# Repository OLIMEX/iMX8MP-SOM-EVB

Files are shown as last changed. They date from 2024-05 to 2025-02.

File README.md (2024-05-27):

# iMX8MP-SOM-EVB

Development board for i.MX8MPlus System on Module with iMX8 SOC

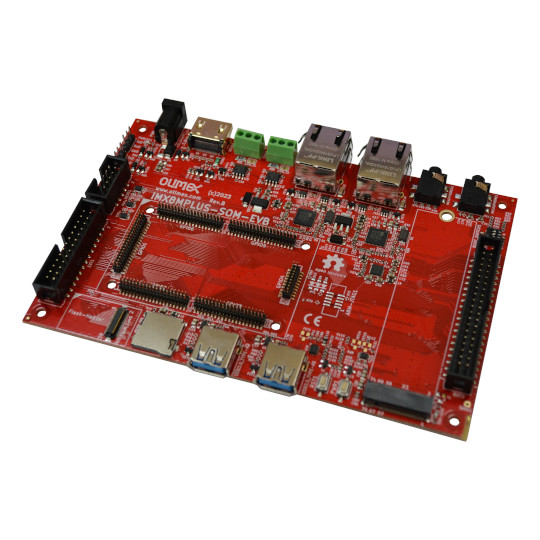
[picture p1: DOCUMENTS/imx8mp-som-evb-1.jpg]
imx8mp-som-evb-1


https://www.olimex.com/Products/SOM/NXP-iMX8/iMX8MP-SOM-EVB-IND/

https://www.olimex.com/Products/SOM/NXP-iMX8/iMX8MP-SOM-4GB-IND/open-source-hardware

## Licensee
* Hardware is released under CERN Open Hardware Licence Version 2 - Strongly Reciprocal
* Software is released under GPL V3 Licensee
* Documentation is released under CC BY-SA 4.0

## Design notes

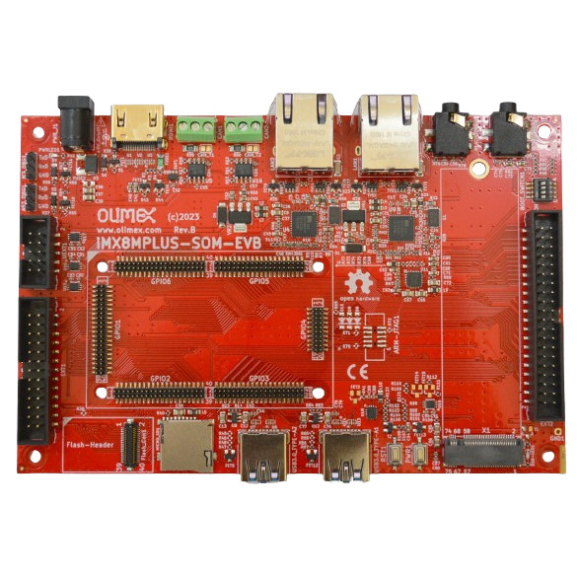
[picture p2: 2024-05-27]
DOCUMENTS/imx8mp-som-evb-2.jpg

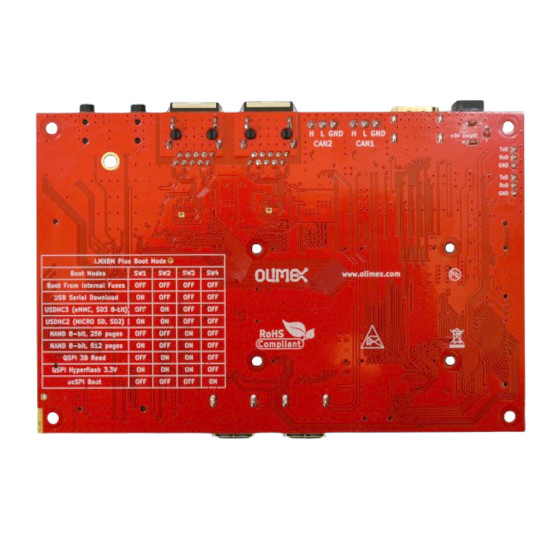
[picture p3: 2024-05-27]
DOCUMENTS/imx8mp-som-evb-3.jpg

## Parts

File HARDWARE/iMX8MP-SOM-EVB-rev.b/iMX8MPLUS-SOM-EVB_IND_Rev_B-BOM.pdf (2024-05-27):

iMX8MPLUS-SOM-EVB_IND_Rev_B | 05/24/2023

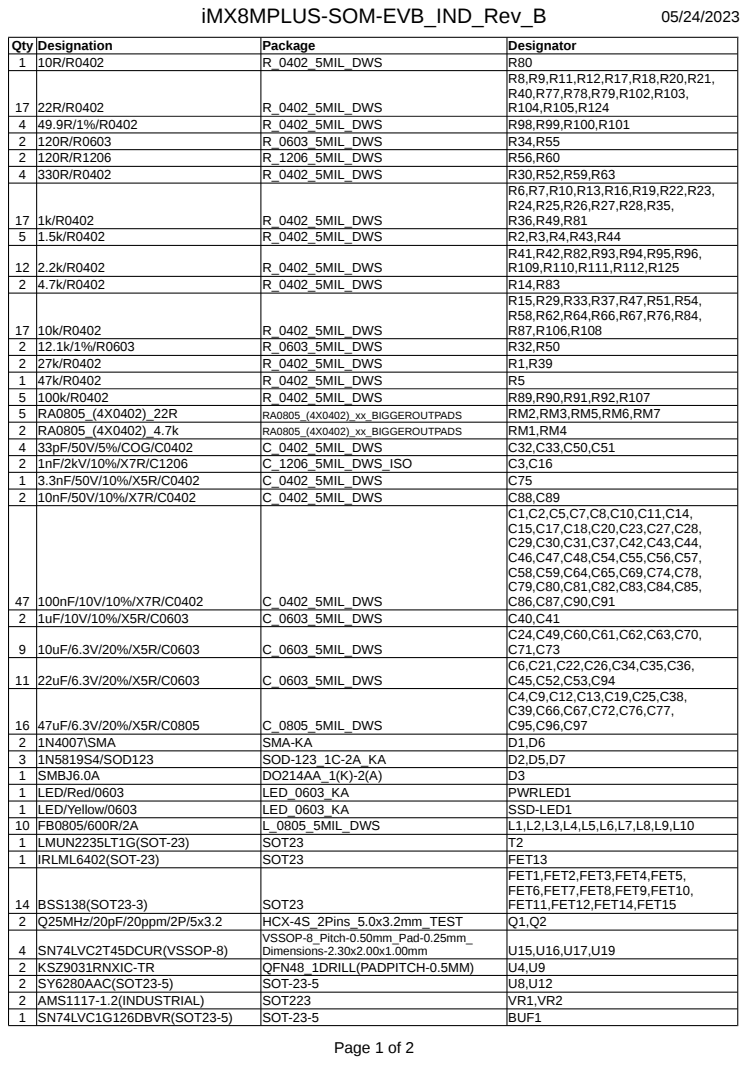
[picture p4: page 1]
Qty Designation; Package; Designator; R_0402_5MIL_DWS; R_0603_5MIL_DWS; R_1206_5MIL_DWS; RA0805_(4X0402)_xx_BIGGEROUTPADS; 4 33pF/50V/5%/COG/C0402; C_0402_5MIL_DWS; C_1206_5MIL_DWS_ISO; C_0603_5MIL_DWS; C_0805_5MIL_DWS; 2 1N4007\SMA; SMA-KA; 3 1N5819S4/SOD123; SOD-123_1C-2A_KA; 1 SMBJ6.0A; 1 LED/Red/0603; LED_0603_KA; PWRLED1; 1 LED/Yellow/0603; SSD-LED1; L_0805_5MIL_DWS; 1 LMUN2235LT1G(SOT-23); SOT23; 1 IRLML6402(SOT-23); FET13; 14 BSS138(SOT23-3); 2 Q25MHz/20pF/20ppm/2P/5x3.2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

iMX8MPLUS-SOM-EVB_IND_Rev_B | 05/24/2023
2 MCP2562-E/SN(SOIC-8_150mil) | SOIC-8_150mil | U5,U10
1 ES8388(QFN28) | QFN28_EP(29)4.076x4.076x0.9mmPitch0.45mm | U11
1 DSC557-0344FE1T(QFN-14) | QFN-14_3.20x2.50x0.9mm_Pitch_0.5mm | U18
1 P-B-V-40-LF | GBH-254-SMT-40 | EXT2
1 P-B-V-10-LF | GBH-254-SMT-10 | UEXT1
5 MALE-PAV16X-2x20-HIGH | GPH127SMT-02X20(PA-V16X-2X20-LF)
1 MALE-PAV16X-2x10-HIGH | GPH127SMT-02X10(PA-V16X-2X10-LF) | GPIO4
2 PJ-3.5-365-3P(SCJ325P00XG0B02G) | SCJ325P00XG0B02G | HEADPHONES1,MICROPHONE1
1 HDMI-SWM-19 | HDMI-SWM-19 | HDMI1
1 Flash_Con[DF12(3.0)-40DS-0.5V(86)] | Flash_Con[DF12(3.0)-40DS-0.5V(86)] | Flash_Con1
2 TM211Q01FM22 | TM211Q01FM22 | LAN1,LAN2
1 MICRO_SD(TFC-WPAPR-08) | TFC-WPAPR-08 | MICRO_SD1
1 PWRJ-2mm(YDJ-1134) | PWRJ-2mm(YDJ-1134) | PWR_J1
2 HN1x3 | HN1x3 | A53_DBG1,M7_DBG1
2 TB3-3.5mm | TB3-3.5mm | CAN1,CAN2
1 B-V-26-LF(GBH254SMT-26) | GBH-254-SMT-26 | EXT1
1 SSD-M2(APCI0107-P001A) | m.2_M(NGFF-W42R-5809-LF) | X1
2 USB-SWZ1BL-9A-LF | USB3.0-TypeA(USB-SWZ1BL-9A-LF)
1 FSMD035 | FUSE-1206 | FUSE1
1 DSHP04TS-S | DSHP04TS-S-1.27mm_Half_4_Slide | BOOT_SWITCH1
2 T1107A(6x3,8x2,5MM) | T1107A(6x3,8x2,5MM) | PWR1,RST1
4 ESDS314DBVR(SOT-23-5) | SOT-23-5 | TVS1,TVS2,TVS3,TVS4
2 Opened | SJ | CAN_T1,CAN_T2
1 NA(5025) | FUSE-5025 | FUSE2
3 NA(RCLAMP0524P(SLP2510P8)) | SLP2510P8_TEST | U1,U2,U3
13 NA/R0402 | R_0402_5MIL_DWS
4 NA(ESD5304D-10/TR) | SLP2510P8_TEST | U6,U7,U13,U14
1 NA(22R/R0402) | R_0402_5MIL_DWS | R38
5 NA(10k/R0402) | R_0402_5MIL_DWS | R65,R68,R69,R70,R71
1 NA(HAB-VCR-010-LF) | HAB-VCR-010-LF | ARM-JTAG1
3 NA(1N5819S4/SOD123) | SOD-123_1C-2A_KA | D8,D9,D10
1 NA(100nF/10V/10%/X7R/C0402) | C_0402_5MIL_DWS | C68
1 NA(R0402) | R_0402_5MIL_DWS | R75
1 NA(2.2k/R0402) | R_0402_5MIL_DWS | R97
2 NA(0R/R0402) | R_0402_5MIL_DWS | R121,R122
1 NA(LMUN2211LT1G(SOT-23)) | SOT23 | T1
1 NA(47uF/6.3V/20%/X5R/C0805) | C_0805_5MIL_DWS | C98

GPIO1,GPIO2,GPIO3,
GPIO5,GPIO6

USB3.0_TYPE-A2,
USB3.0_TYPE-A1

R31,R45,R46,R48,R53,R57,R61, R72,R73,R74,R85,R86,R88

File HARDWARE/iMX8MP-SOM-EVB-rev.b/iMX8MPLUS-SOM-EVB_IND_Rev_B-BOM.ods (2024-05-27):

Qty | Designation | Package | Designator
1 | 10R/R0402 | R_0402_5MIL_DWS | R80
17 | 22R/R0402 | R_0402_5MIL_DWS | R8,R9,R11,R12,R17,R18,R20,R21, R40,R77,R78,R79,R102,R103, R104,R105,R124
4 | 49.9R/1%/R0402 | R_0402_5MIL_DWS | R98,R99,R100,R101
2 | 120R/R0603 | R_0603_5MIL_DWS | R34,R55
2 | 120R/R1206 | R_1206_5MIL_DWS | R56,R60
4 | 330R/R0402 | R_0402_5MIL_DWS | R30,R52,R59,R63
17 | 1k/R0402 | R_0402_5MIL_DWS | R6,R7,R10,R13,R16,R19,R22,R23, R24,R25,R26,R27,R28,R35, R36,R49,R81
5 | 1.5k/R0402 | R_0402_5MIL_DWS | R2,R3,R4,R43,R44
12 | 2.2k/R0402 | R_0402_5MIL_DWS | R41,R42,R82,R93,R94,R95,R96, R109,R110,R111,R112,R125
2 | 4.7k/R0402 | R_0402_5MIL_DWS | R14,R83
17 | 10k/R0402 | R_0402_5MIL_DWS | R15,R29,R33,R37,R47,R51,R54, R58,R62,R64,R66,R67,R76,R84, R87,R106,R108
2 | 12.1k/1%/R0603 | R_0603_5MIL_DWS | R32,R50
2 | 27k/R0402 | R_0402_5MIL_DWS | R1,R39
1 | 47k/R0402 | R_0402_5MIL_DWS | R5
5 | 100k/R0402 | R_0402_5MIL_DWS | R89,R90,R91,R92,R107
5 | RA0805_(4X0402)_22R | RA0805_(4X0402)_xx_BIGGEROUTPADS | RM2,RM3,RM5,RM6,RM7
2 | RA0805_(4X0402)_4.7k | RA0805_(4X0402)_xx_BIGGEROUTPADS | RM1,RM4
4 | 33pF/50V/5%/COG/C0402 | C_0402_5MIL_DWS | C32,C33,C50,C51
2 | 1nF/2kV/10%/X7R/C1206 | C_1206_5MIL_DWS_ISO | C3,C16
1 | 3.3nF/50V/10%/X5R/C0402 | C_0402_5MIL_DWS | C75
2 | 10nF/50V/10%/X7R/C0402 | C_0402_5MIL_DWS | C88,C89
47 | 100nF/10V/10%/X7R/C0402 | C_0402_5MIL_DWS | C1,C2,C5,C7,C8,C10,C11,C14, C15,C17,C18,C20,C23,C27,C28, C29,C30,C31,C37,C42,C43,C44, C46,C47,C48,C54,C55,C56,C57, C58,C59,C64,C65,C69,C74,C78, C79,C80,C81,C82,C83,C84,C85, C86,C87,C90,C91
2 | 1uF/10V/10%/X5R/C0603 | C_0603_5MIL_DWS | C40,C41
9 | 10uF/6.3V/20%/X5R/C0603 | C_0603_5MIL_DWS | C24,C49,C60,C61,C62,C63,C70, C71,C73
11 | 22uF/6.3V/20%/X5R/C0603 | C_0603_5MIL_DWS | C6,C21,C22,C26,C34,C35,C36, C45,C52,C53,C94
16 | 47uF/6.3V/20%/X5R/C0805 | C_0805_5MIL_DWS | C4,C9,C12,C13,C19,C25,C38, C39,C66,C67,C72,C76,C77, C95,C96,C97
2 | 1N4007\SMA | SMA-KA | D1,D6
3 | 1N5819S4/SOD123 | SOD-123_1C-2A_KA | D2,D5,D7
1 | SMBJ6.0A | DO214AA_1(K)-2(A) | D3
1 | LED/Red/0603 | LED_0603_KA | PWRLED1
1 | LED/Yellow/0603 | LED_0603_KA | SSD-LED1
10 | FB0805/600R/2A | L_0805_5MIL_DWS | L1,L2,L3,L4,L5,L6,L7,L8,L9,L10
1 | LMUN2235LT1G(SOT-23) | SOT23 | T2
1 | IRLML6402(SOT-23) | SOT23 | FET13
14 | BSS138(SOT23-3) | SOT23 | FET1,FET2,FET3,FET4,FET5, FET6,FET7,FET8,FET9,FET10, FET11,FET12,FET14,FET15
2 | Q25MHz/20pF/20ppm/2P/5x3.2 | HCX-4S_2Pins_5.0x3.2mm_TEST | Q1,Q2
4 | SN74LVC2T45DCUR(VSSOP-8) | VSSOP-8_Pitch-0.50mm_Pad-0.25mm_ Dimensions-2.30x2.00x1.00mm | U15,U16,U17,U19
2 | KSZ9031RNXIC-TR | QFN48_1DRILL(PADPITCH-0.5MM) | U4,U9
2 | SY6280AAC(SOT23-5) | SOT-23-5 | U8,U12
2 | AMS1117-1.2(INDUSTRIAL) | SOT223 | VR1,VR2
1 | SN74LVC1G126DBVR(SOT23-5) | SOT-23-5 | BUF1
2 | MCP2562-E/SN(SOIC-8_150mil) | SOIC-8_150mil | U5,U10
1 | ES8388(QFN28) | QFN28_EP(29)4.076x4.076x0.9mmPitch0.45mm | U11
1 | DSC557-0344FE1T(QFN-14) | QFN-14_3.20x2.50x0.9mm_Pitch_0.5mm | U18
1 | P-B-V-40-LF | GBH-254-SMT-40 | EXT2
1 | P-B-V-10-LF | GBH-254-SMT-10 | UEXT1
5 | MALE-PAV16X-2x20-HIGH | GPH127SMT-02X20(PA-V16X-2X20-LF) | GPIO1,GPIO2,GPIO3, GPIO5,GPIO6
1 | MALE-PAV16X-2x10-HIGH | GPH127SMT-02X10(PA-V16X-2X10-LF) | GPIO4
2 | PJ-3.5-365-3P(SCJ325P00XG0B02G) | SCJ325P00XG0B02G | HEADPHONES1,MICROPHONE1
1 | HDMI-SWM-19 | HDMI-SWM-19 | HDMI1
1 | Flash_Con[DF12(3.0)-40DS-0.5V(86)] | Flash_Con[DF12(3.0)-40DS-0.5V(86)] | Flash_Con1
2 | TM211Q01FM22 | TM211Q01FM22 | LAN1,LAN2
1 | MICRO_SD(TFC-WPAPR-08) | TFC-WPAPR-08 | MICRO_SD1
1 | PWRJ-2mm(YDJ-1134) | PWRJ-2mm(YDJ-1134) | PWR_J1
2 | HN1x3 | HN1x3 | A53_DBG1,M7_DBG1
2 | TB3-3.5mm | TB3-3.5mm | CAN1,CAN2
1 | B-V-26-LF(GBH254SMT-26) | GBH-254-SMT-26 | EXT1
1 | SSD-M2(APCI0107-P001A) | m.2_M(NGFF-W42R-5809-LF) | X1
2 | USB-SWZ1BL-9A-LF | USB3.0-TypeA(USB-SWZ1BL-9A-LF) | USB3.0_TYPE-A2, USB3.0_TYPE-A1
1 | FSMD035 | FUSE-1206 | FUSE1
1 | DSHP04TS-S | DSHP04TS-S-1.27mm_Half_4_Slide | BOOT_SWITCH1
2 | T1107A(6x3,8x2,5MM) | T1107A(6x3,8x2,5MM) | PWR1,RST1
4 | ESDS314DBVR(SOT-23-5) | SOT-23-5 | TVS1,TVS2,TVS3,TVS4
2 | Opened | SJ | CAN_T1,CAN_T2
1 | NA(5025) | FUSE-5025 | FUSE2
3 | NA(RCLAMP0524P(SLP2510P8)) | SLP2510P8_TEST | U1,U2,U3
13 | NA/R0402 | R_0402_5MIL_DWS | R31,R45,R46,R48,R53,R57,R61, R72,R73,R74,R85,R86,R88
4 | NA(ESD5304D-10/TR) | SLP2510P8_TEST | U6,U7,U13,U14
1 | NA(22R/R0402) | R_0402_5MIL_DWS | R38
5 | NA(10k/R0402) | R_0402_5MIL_DWS | R65,R68,R69,R70,R71
1 | NA(HAB-VCR-010-LF) | HAB-VCR-010-LF | ARM-JTAG1
3 | NA(1N5819S4/SOD123) | SOD-123_1C-2A_KA | D8,D9,D10
1 | NA(100nF/10V/10%/X7R/C0402) | C_0402_5MIL_DWS | C68
1 | NA(R0402) | R_0402_5MIL_DWS | R75
1 | NA(2.2k/R0402) | R_0402_5MIL_DWS | R97
2 | NA(0R/R0402) | R_0402_5MIL_DWS | R121,R122
1 | NA(LMUN2211LT1G(SOT-23)) | SOT23 | T1
1 | NA(47uF/6.3V/20%/X5R/C0805) | C_0805_5MIL_DWS | C98

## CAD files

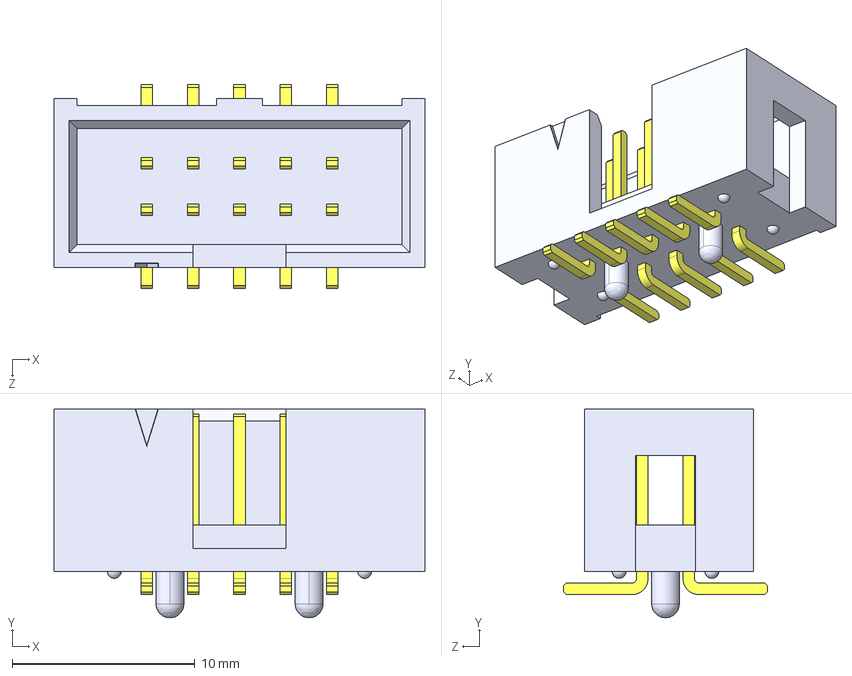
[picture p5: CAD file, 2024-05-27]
HARDWARE/iMX8MP-SOM-EVB-rev.b/3d/UEXT-SMD.STEP
20.3 x 11.4 x 11.2 mm
User Library-HTST-105-01-F-DV-A__HTST-105-01-DV-A_header
User Library-HTST-105-01-F-DV-A__HTST-First_Position_Indicator
User Library-HTST-105-01-F-DV-A__T-1S6-05-01-DV_

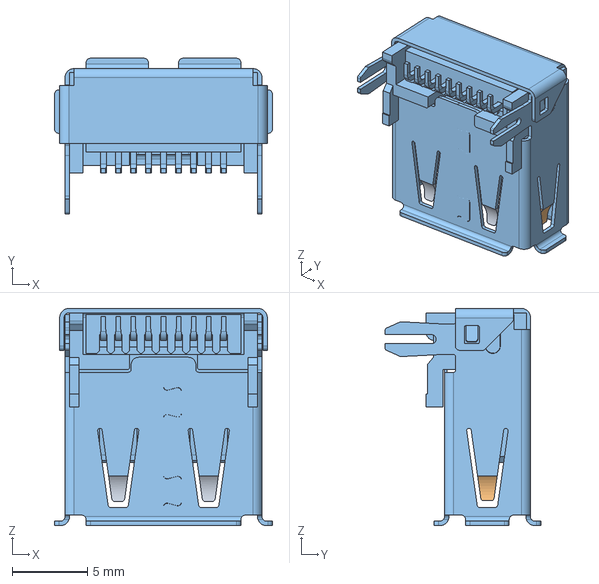
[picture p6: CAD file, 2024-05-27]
HARDWARE/iMX8MP-SOM-EVB-rev.b/3d/USB3.0-TypeA_SWZ1BL-9A.stp
14.5 x 10.3 x 14.4 mm

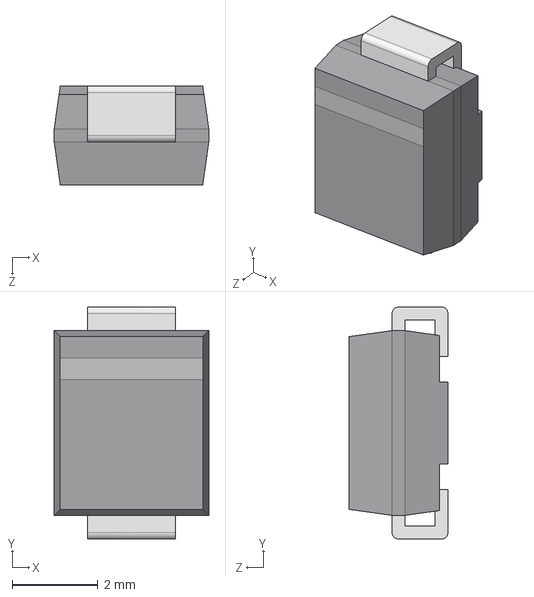
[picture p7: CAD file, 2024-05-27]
HARDWARE/iMX8MP-SOM-EVB-rev.b/3d/DO-214AA_SMB.step
3.60 x 5.40 x 2.30 mm

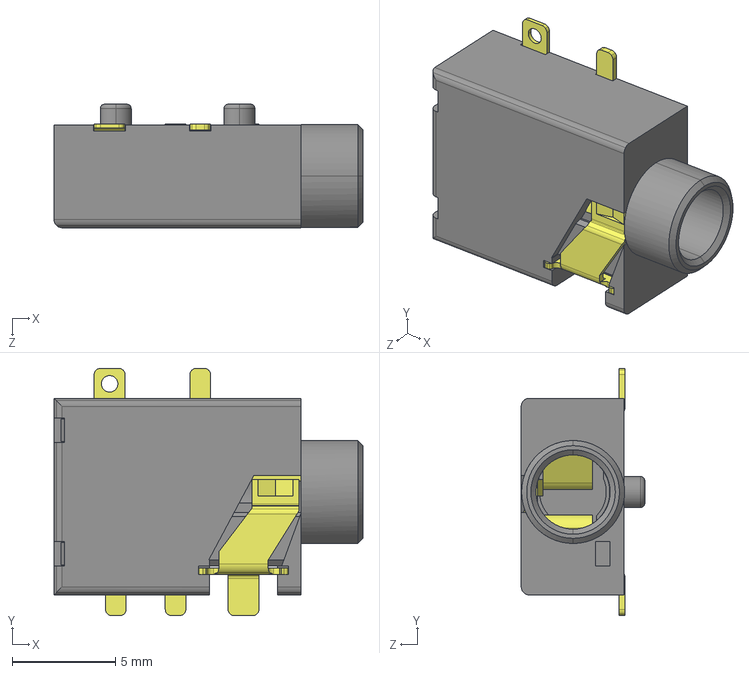
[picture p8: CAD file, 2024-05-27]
HARDWARE/iMX8MP-SOM-EVB-rev.b/3d/Audio_Jack-3.5mm---CUI_SJ1-3515-SMT-TR.step
15.0 x 12.0 x 6.00 mm

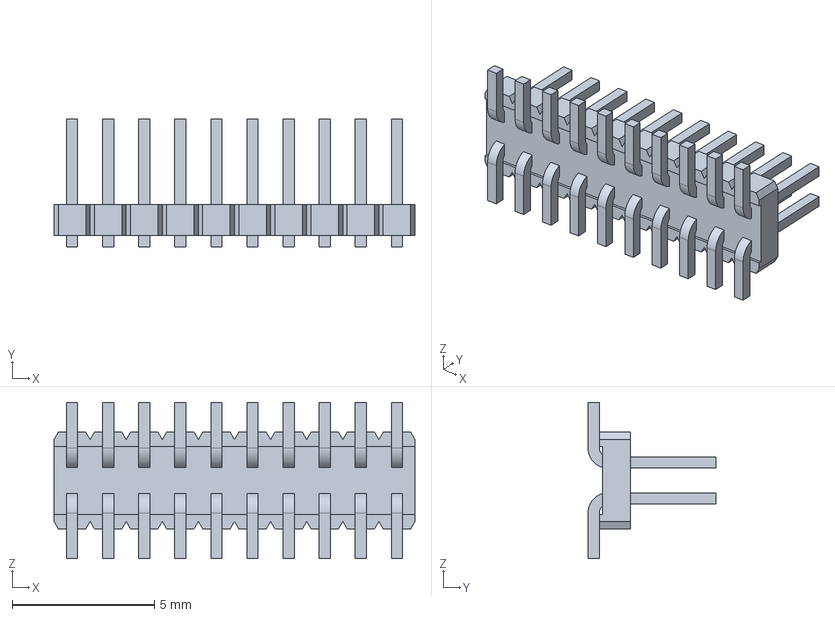
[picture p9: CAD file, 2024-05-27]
HARDWARE/iMX8MP-SOM-EVB-rev.b/3d/20PinMaleSmt.stp
12.7 x 4.50 x 5.50 mm

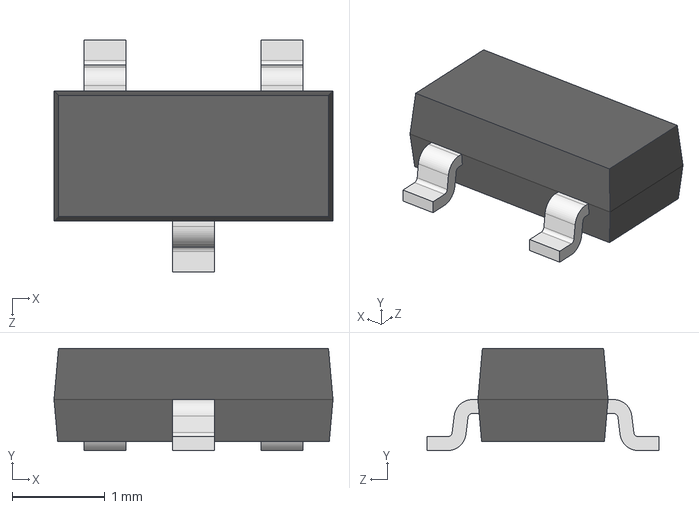
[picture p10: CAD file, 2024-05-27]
HARDWARE/iMX8MP-SOM-EVB-rev.b/3d/SOT-23.step
3.00 x 1.10 x 2.50 mm

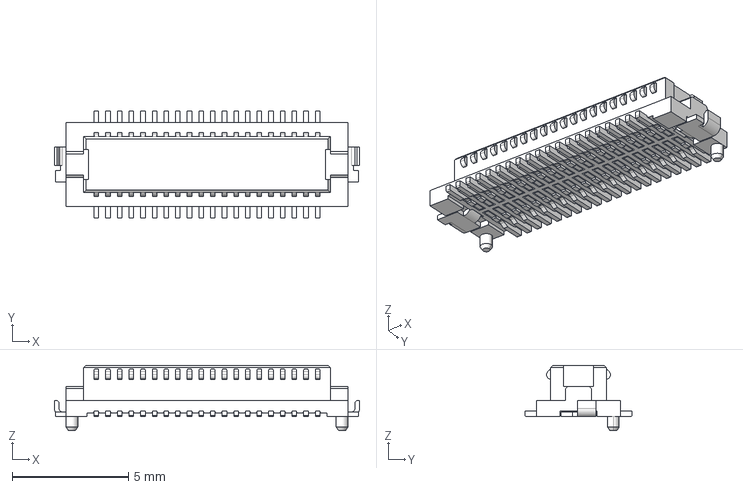
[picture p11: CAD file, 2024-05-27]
HARDWARE/iMX8MP-SOM-EVB-rev.b/3d/DF12(3.0)-40DS-0.5V.stp
13.1 x 4.60 x 2.80 mm

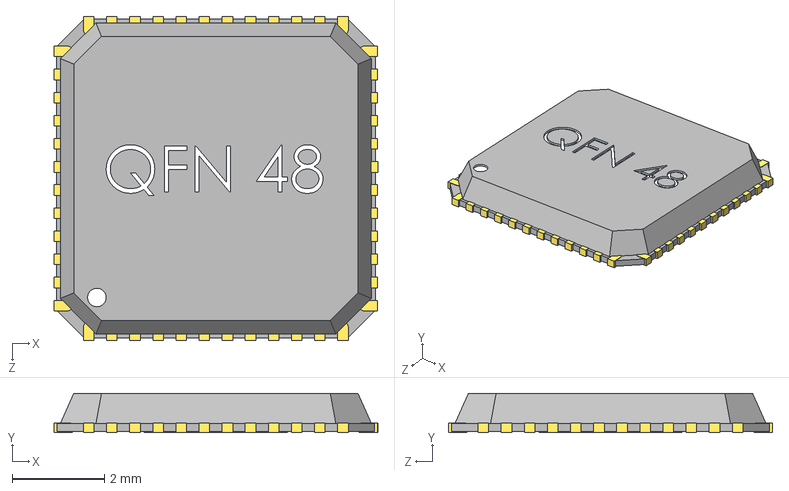
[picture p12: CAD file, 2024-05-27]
HARDWARE/iMX8MP-SOM-EVB-rev.b/3d/QFN48-0.5.STEP
7.00 x 0.85 x 7.01 mm
User Library-QFN48-1_Body
User Library-QFN48-1_Pins

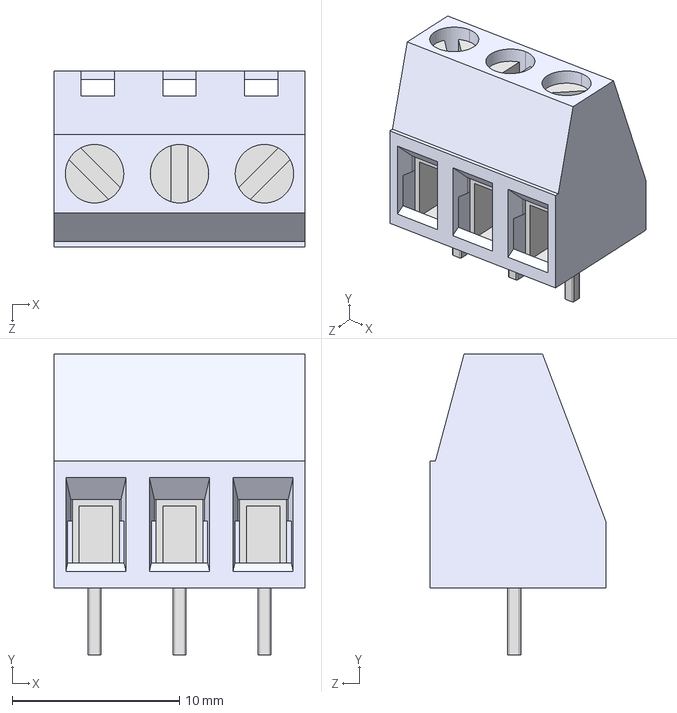
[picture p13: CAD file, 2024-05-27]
HARDWARE/iMX8MP-SOM-EVB-rev.b/3d/klema-5mm-3pin.step
15.0 x 18.0 x 10.5 mm

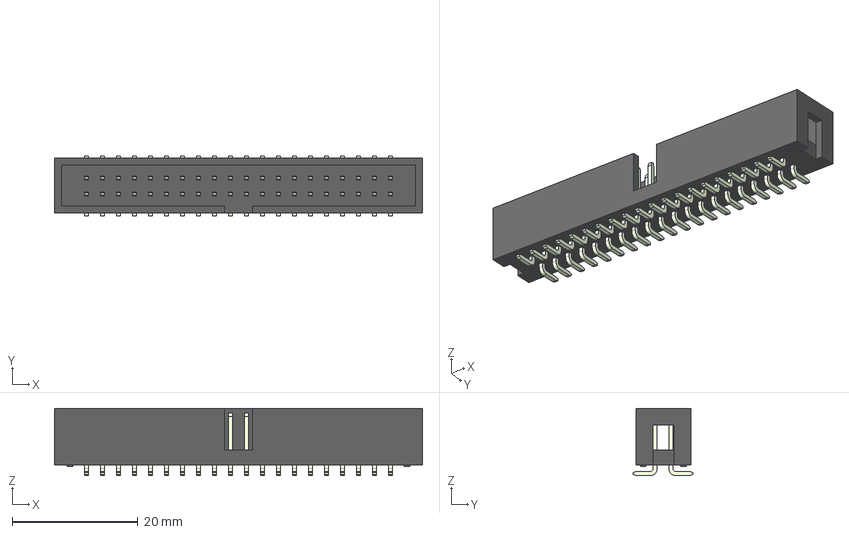
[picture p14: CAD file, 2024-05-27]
HARDWARE/iMX8MP-SOM-EVB-rev.b/3d/GBH254SMT-40(B-V-40-LF).stp
58.4 x 9.50 x 10.6 mm

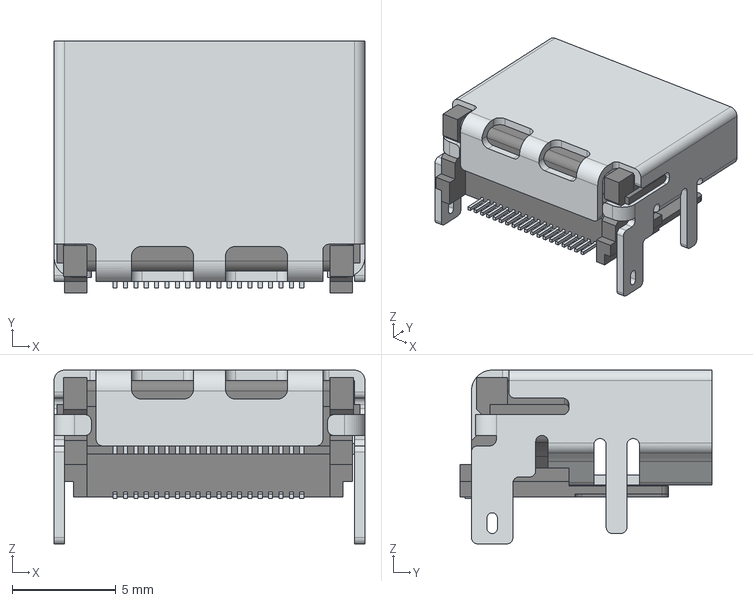
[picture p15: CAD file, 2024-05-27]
HARDWARE/iMX8MP-SOM-EVB-rev.b/3d/HDMI_19POS_SMD_Wurth_Electronic-685119134923.stp
15.0 x 12.2 x 8.38 mm

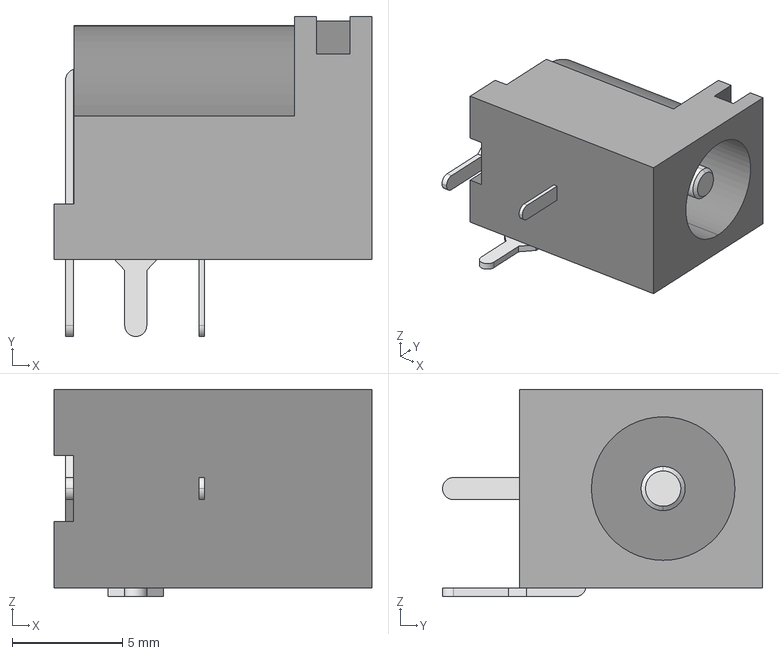
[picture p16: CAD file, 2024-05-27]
HARDWARE/iMX8MP-SOM-EVB-rev.b/3d/pj-102ah.stp
14.4 x 14.5 x 9.40 mm

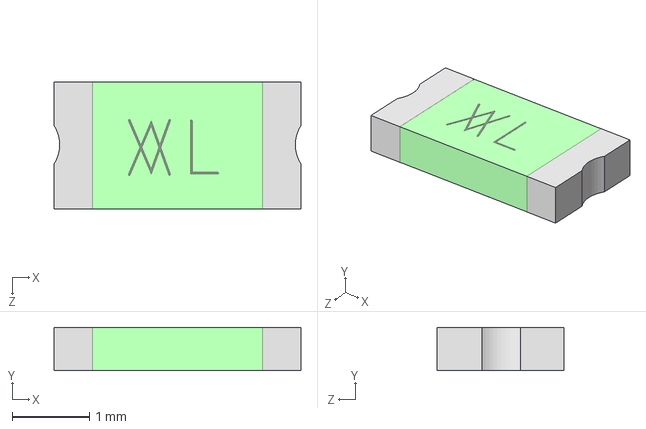
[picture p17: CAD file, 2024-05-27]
HARDWARE/iMX8MP-SOM-EVB-rev.b/3d/SMD075F.step
3.20 x 0.562 x 1.65 mm

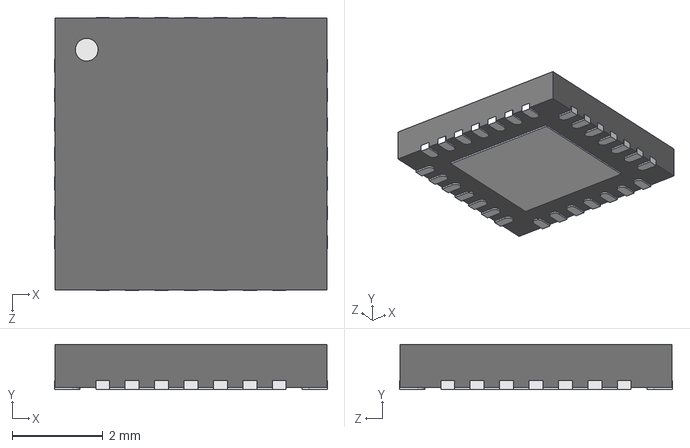
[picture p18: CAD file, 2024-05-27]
HARDWARE/iMX8MP-SOM-EVB-rev.b/3d/QFN-28(6.0x6.0x1.0mm_P0.65mm).STEP
6.02 x 1.00 x 6.02 mm

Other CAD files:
HARDWARE/iMX8MP-SOM-EVB-rev.b/3d/GBH2x5.stp
HARDWARE/iMX8MP-SOM-EVB-rev.b/3d/DO-214AC_SMA.step
HARDWARE/iMX8MP-SOM-EVB-rev.b/3d/SOT-23-5.step
HARDWARE/iMX8MP-SOM-EVB-rev.b/3d/TFC-WPAPR-08---112J-TXAR-R_C_1-1.STEP
HARDWARE/iMX8MP-SOM-EVB-rev.b/3d/40PinMaleSMD.stp
HARDWARE/iMX8MP-SOM-EVB-rev.b/3d/434121043836 (rev1).stp
HARDWARE/iMX8MP-SOM-EVB-rev.b/3d/Connector_1Port_RJ45_Magjack_10-100Base-T_AutoMDIX_Molex-0934635206_DigiKey-WM17614-ND.stp
HARDWARE/iMX8MP-SOM-EVB-rev.b/3d/GPH2x13.stp
HARDWARE/iMX8MP-SOM-EVB-rev.b/3d/HN1x3-PinHeader_1x03_P2.54mm_Vertical.step
HARDWARE/iMX8MP-SOM-EVB-rev.b/3d/M.2(NGFF)_Series_67-Contacts.stp
HARDWARE/iMX8MP-SOM-EVB-rev.b/3d/QFN-14_3.20x2.50mm(ASEMCC2-ZR-T3).STEP
HARDWARE/iMX8MP-SOM-EVB-rev.b/3d/SLP2510P8.step
HARDWARE/iMX8MP-SOM-EVB-rev.b/3d/SMD5032.STEP
HARDWARE/iMX8MP-SOM-EVB-rev.b/3d/SO-8_150mil---SN65HVDA1050AQDRQ1.STEP
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

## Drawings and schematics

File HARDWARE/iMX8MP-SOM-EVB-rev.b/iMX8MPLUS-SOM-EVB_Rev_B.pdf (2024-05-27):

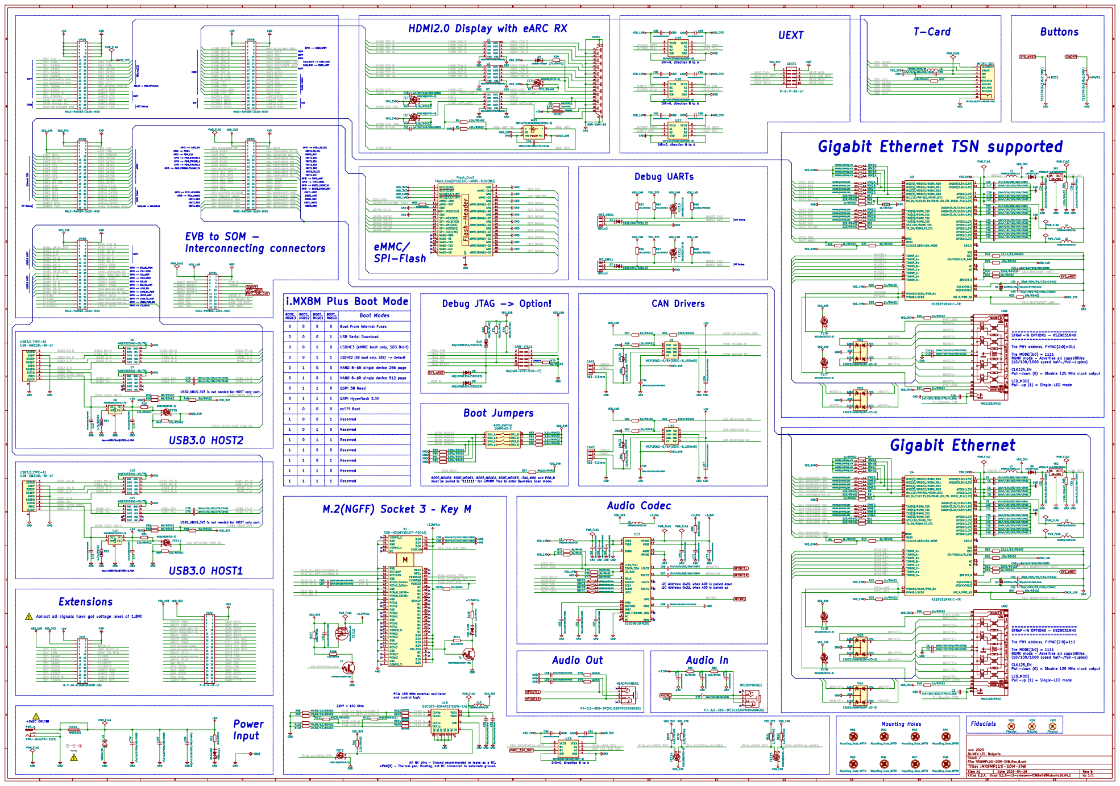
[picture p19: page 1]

8 OUT2 | HDMI_TX1_P

HDMI_TX2_N

8 OUT2 | HDMI_TXC_P
7 GND 6 OUT3 | HDMI_TXC_N

8 OUT2 | HSDA | 16
7 GND 6 OUT3 | | 17

GPIO -> DSI_BL_PWM
GPIO -> CSI1_SYNC GPIO -> CSI_nRST GPIO -> CSI2_SYNC GPIO -> DSI_EN GPIO -> DSI_TS_nINT GPIO -> LVDS_EN GPIO -> LVDS_BL_PWM

INT_N/PME_N2
DA+ DA- DB+ DB- DC+ DC- DD+ DD- GREEN

Boot From Internal Fuses

0 VBUS 1 USBDN 2 USBDP 3 GNDP 4 SSRXN 5 SSRXP 6 GNDD 7 SSTXN 8 SSTXP 9 USB3.0_TYPE-A2
USB-SWZ1BL-9A-LF

====================== The PHY address, PHYAD[2:0]=011

USDHC2 (SD boot only, SD2) -> Default

NAND 8-bit single device 256 page

Pull-down (0) = Disable 125 MHz clock output
LED_MODE
Pull-up (1) = Single-LED mode

NAND 8-bit single device 512 page

USB2_VBUS_3V3 is not needed for HOST only port.

0 VBUS 1 USBDN 2 USBDP 3 GNDP 4 SSRXN 5 SSRXP 6 GNDD 7 SSTXN 8 SSTXP 9 USB3.0_TYPE-A1

must be pulled to "111111" for i.MX8M Plus to enter Boundary Scan mode.

I2C Address: 0x22, when AD0 is pulled up

====================== The PHY address, PHYAD[2:0]=111

7 CLK1p 8 CLK1n 9 U18 DSC557-0344FE1T(QFN-14) GND C88 10nF/50V/10%/X7R/C0402 C89 10nF/50V/10%/X7R/C0402 GND GND

All NC pins - Ground recommended or leave as a NC.

ePAD(0) - Thermal pad, floating, not DC connected to substrate ground.

Id: 1/1 Title: iMX8MPLUS-SOM-EVB

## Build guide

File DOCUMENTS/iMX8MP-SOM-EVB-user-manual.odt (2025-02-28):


IMX8MP-SOM-EVB

User Manual

document revision 2.0 www.olimex.com

# What is iMX8MP-SOM-EVB

iMX8MP-SOM-EVB (https://www.olimex.com/Products/SOM/NXP-iMX8/iMX8MP-SOM-EVB-IND/) is an expansion board for easier evaluation of iMX8MP-SOM (https://www.olimex.com/Products/SOM/NXP-iMX8/iMX8MP-SOM-4GB-IND/open-source-hardware) system-on-module development board. It has:

- iMX8MP-SOM matching connectors
- Two Gigabit Ethernet connectors
- Two CAN transceivers
- HDMI output connector
- Power jack for 5V DC
- Two serial debug UARTs (for A53 and M7)
- Micro SD-card connector
- Flash module connector
- USB 3.0 hosts
- PCI Express 3.0 M.2 expansion slot (2280) for nVME
- Headphone 3.5mm connector
- Microphone 3.5 mm connector
- Reset button
- PWR button
- UEXT connector
- Two GPIO connectors
- Optional ARM JTAG connector
- Boot slide switch
- Industrial grade temperature range: (-45+85)C
- Dimensions: (155 x 102)mm
- Open-hardware design, all original design files available, design made with KiCAD

## Order codes for iMX8MP-SOM-EVB and accessories

iMX8MP-SOM-EVB (https://www.olimex.com/Products/SOM/NXP-iMX8/iMX8MP-SOM-EVB-IND/) Expansion board for easy evaluation of iMX8MP-SOM which can be used as reference design; requires SOM module iMX8MP- SOM-4GB-IND

iMX8MP-SOM-4GB-IND (https://www.olimex.com/Products/SOM/NXP-iMX8/iMX8MP-SOM-4GB-IND/open-source-hardware) Main module with i.MX8 quad-core MIMX8ML8CVNKZAB, 4GB LPDDR4, EEPROM, PMIC

MICRO-SD-16GB-CLASS10 (https://www.olimex.com/Products/Components/Storage/MICRO-SD-16GB-CLASS10/) Blank 16GB microSD card

USB-CARD-READER (https://www.olimex.com/Products/USB-Modules/USB-CARD-READER/) USB card reader and writer

SY1505E (https://www.olimex.com/Products/Power/SY1505E/) Power adapter 5V 3A

SY2005E (https://www.olimex.com/Products/Power/SY2005E/) Power adapter 5V 5A

USB-SERIAL-F (https://www.olimex.com/Products/Components/Cables/USB-Serial-Cable/USB-SERIAL-F/) Serial debug cable for console log

Flash-e32Gs16M (https://www.olimex.com/Products/OLinuXino/Accessories/Flash-e32Gs16M/) Plug-and-play eMMC and SPI memory expansion module

CABLE-HDMI-50CM (https://www.olimex.com/Products/Components/Cables/CABLE-HDMI-50CM/) HDMI cable

USB-KEYBOARD-PS2 (https://www.olimex.com/Products/USB-Modules/USB-KEYBOARD-PS2/) Mini keyboard

PWR-CABLE (https://www.olimex.com/Products/Components/Cables/PWR-CABLE/) Cable with free leads fitting the Olimex barrel jacks

UEXT modules (https://www.olimex.com/Products/Modules/) There are temperature, humidity, pressure, magnetic field, light sensors. Modules with LCDs, LED matrix, Relays, Bluetooth, Zigbee, WiFi, GSM, GPS, RFID, RTC, EKG, sensors and etc.

# HARDWARE

## iMX8MP-SOM-EVB layout


Flash module

MicroSD card

USB3 hosts

Reset Power Buttons

M.2 nVM slot

Power +5V

HDMI

CAN

Gigabit Ethernet

Audio

Boot

GPIO

UEXT

GPIO

Debug

Optional JTAG

## iMX8MP-SOM-EVB schematics

Latest PDF export of schematic is available at GitHub:

iMX8MP-SOM-EVB schematic PDF (https://github.com/OLIMEX/iMX8MP-SOM-EVB/blob/main/HARDWARE/iMX8MP-SOM-EVB-rev.b/iMX8MPLUS-SOM-EVB_Rev_B.pdf)

All design files and sources are again available at the GitHub page (https://github.com/OLIMEX/iMX8MP-SOM-EVB/tree/main/HARDWARE) of the device.

## iMX8MP-SOM-EVB connectors

### UEXT1 connector

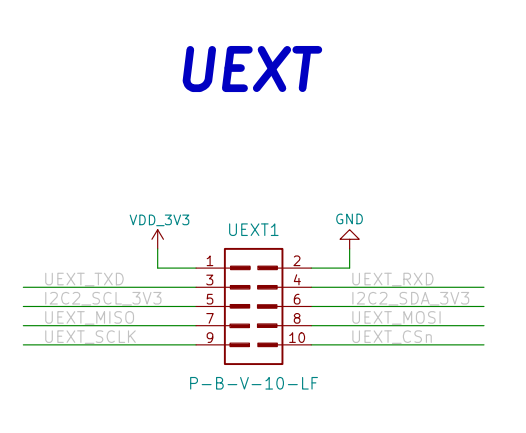
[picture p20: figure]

### Micro_SD1 connector

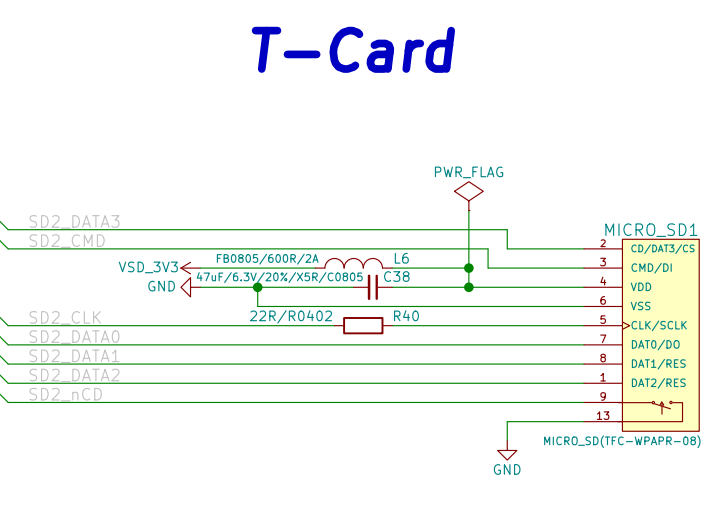
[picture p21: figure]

### Buttons

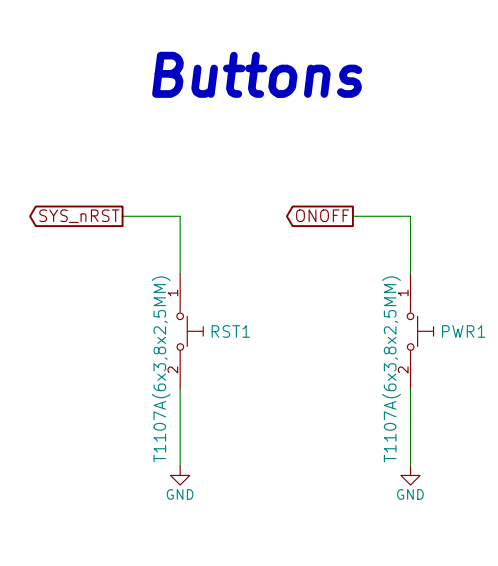
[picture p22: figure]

### EXT1 header

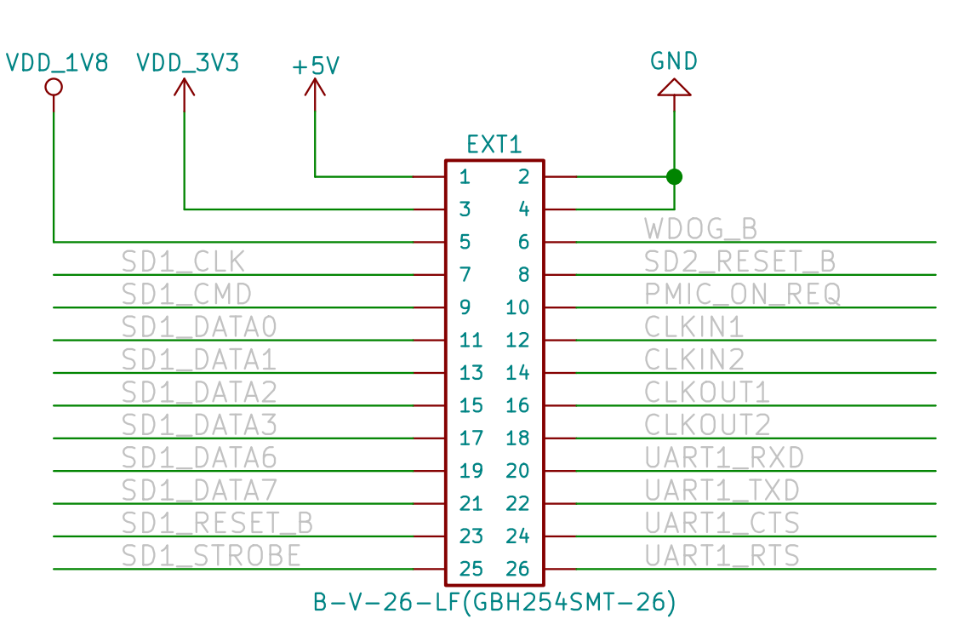
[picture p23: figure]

### EXT2 header

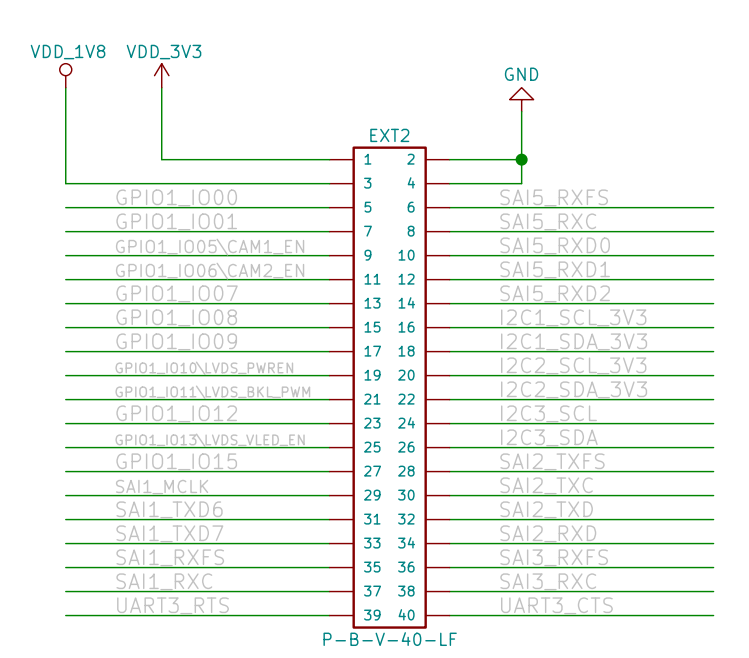
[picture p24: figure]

### PCI 3.0 M.2 (2280) nVME

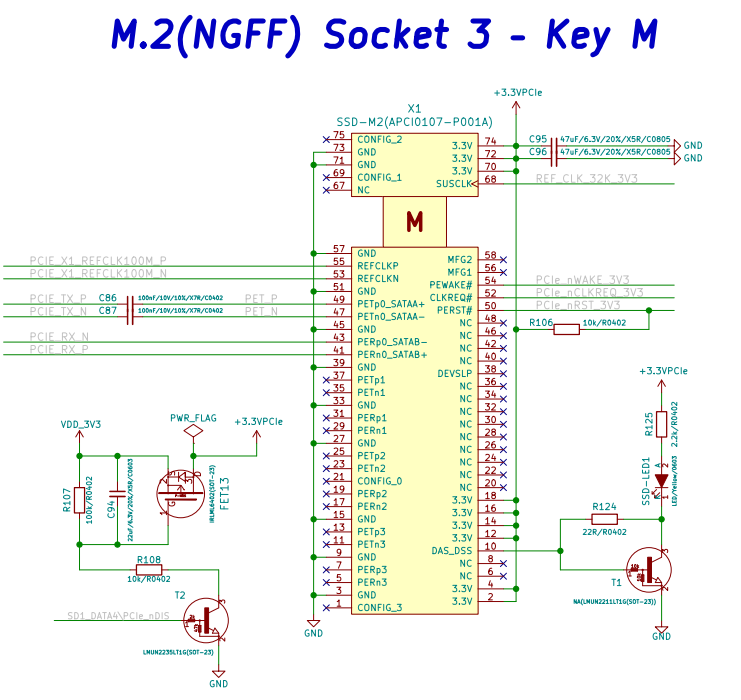
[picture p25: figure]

### Audio out

HEADPHONES1 jack is handled by ES8388 audio driver. It is currently not supported in the official Linux images.

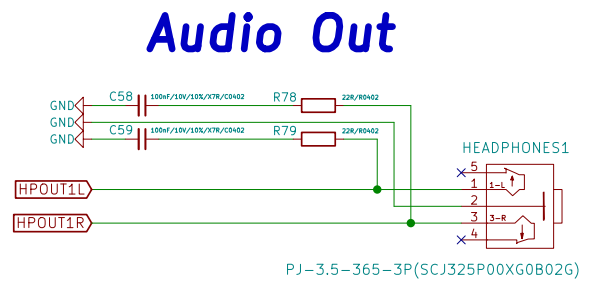
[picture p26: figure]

### Audio in

MICROPHONE1 jack is handled by ES8388 audio driver. It is currently not supported in the official Linux images.

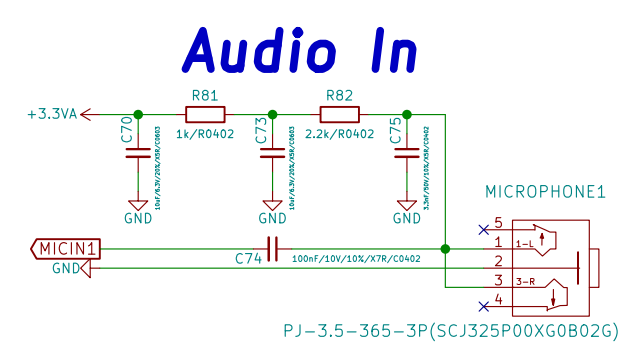
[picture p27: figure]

# SOFTWARE

You can find Olimex-maintained recommended images here:

# Recommended Olimage Linux images (https://images.olimex.com/release/imx8mp/)

It is recommended to start with the base Armbian image. The minimal Armbian image has no graphical user interface.

The software we provide and maintain for iMX8MP-SOM-EVB is the same as for the main board:

- Armbian-based Debian 12 “bookworm” images (base and minimal) with support for the main chip and most peripherals, like USB 3.0, GbE, NVMe M.2 slot, Flash-header slot, serial debug, HDMI output (+audio over HDMI), CAN, etc. Known software issues: Currently there is no support for the ES8388 audio driver, e.g. HEADPHONES1 and MICROPHONE1 jacks won’t work without additional software work (HDMI audio works ok).

- Buildroot setup

# Document Revision History

Revision 2.0 February 2025:

- removed misleading information about recommended LCD

- fixed links

- added info about Armbian-based Debian image

Revision 1.0 May 2024

- initial document release
